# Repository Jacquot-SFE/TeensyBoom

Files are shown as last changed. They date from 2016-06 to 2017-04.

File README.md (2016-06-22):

TEENSYBOOM
---
Teensy 3.2 analog emulation drum machine.

# Organization

Supposedly all of the design artifacts will wind up in here.

If it's not here, go check the ol' [synth-drum]() repo.  It's a mess, be warned.

* **/chassis/** files for the cheek blocks & control panel
* **/TeensyBoomVoiceLibrary/** source files for the Teensy-audio-based library
* **/TeensyBoom/** the sketch files for the sequencer and stuff
* **/demo-patterns/** Some pattern files captured after playing with the sequencer a bit.  For use when you get sick of the default pattern.
* **/Documentation/** ha ha.  

## Setup & Configuration

Developed using Arduino IDE 1.6.5.  Last time I tried a newer built, it rebuilt everything everytime I clicked 'go.'

Loading using Teensy Loader 1.28.

### Installation:

Copy the _TeensyVoiceLibrary_ files to your local Arduino library directory (for me , it's C:\Users\redacted\Documents\Arduino\libraries\TeensyBoomVoiceLibrary).

Remove or rename the AudioSynthSimpleDrum in the teensy audio directory (C:\Users\byron.jacquot\Documents\Arduino\libraries\Audio\synth_simple_drum.cpp and .h).  The Boom library contains a newer version.

### Compile and Load:

I've been building for 72 MHz, non-optimized, with the assumption that we can always bump up to optimization & overclocking if we run out of resources.  It's harder to go the other way!

License Information
-------------------

This product is _**open source**_!

Please review the LICENSE.md file for license information.

Distributed as-is; no warranty is given.

It heavily leverages all of the infrastructure developed by [PJRC.com](PJRC.com).  Please support them by purchasing genuine Teensy components!  _Alibaba Teensys aren't Teensies!_

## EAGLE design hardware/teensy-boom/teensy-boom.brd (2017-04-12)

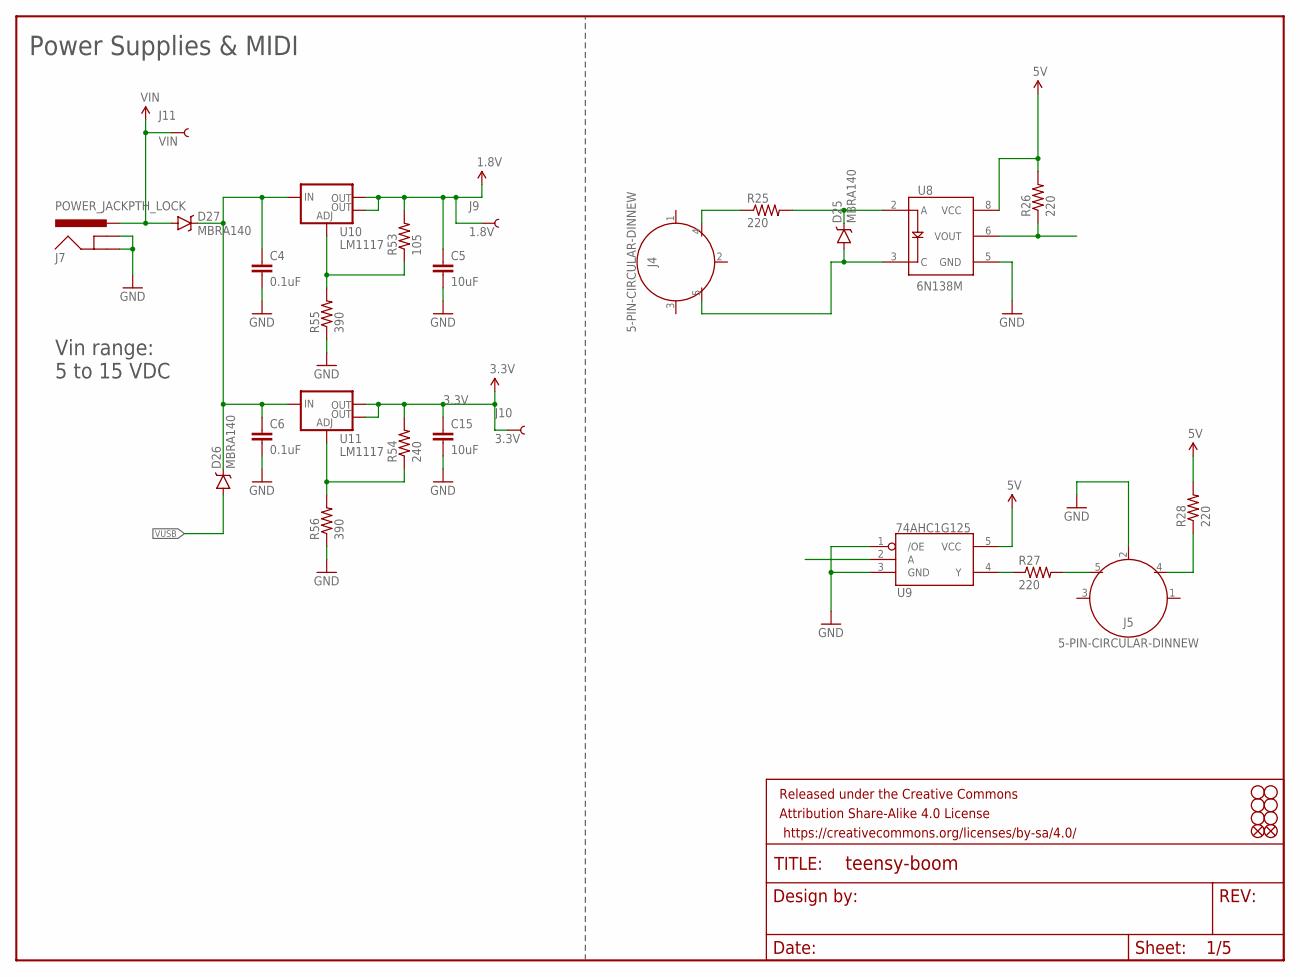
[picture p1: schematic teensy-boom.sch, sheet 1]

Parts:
C4, C6: 0.1uF; 0603-CAP
C5, C15: 10uF; 0603-CAP
D25, D26, D27: MBRA140; SMA-DIODE
FD1, FD2: FIDUCIALUFIDUCIAL; MICRO-FIDUCIAL
FRAME2: FRAME-LETTERNO_PACKAGE; DUMMY
H1, H2, H3, H4, H5, H6: STAND-OFF
J4, J5: 5-PIN-CIRCULAR-DINNEW; 5-PIN-DIN-RA-PCB-NEW
J7: POWER_JACKPTH_LOCK; POWER_JACK_PTH_LOCK
J9: 1.8V; TP_15TH
J10: 3.3V; TP_15TH
J11: VIN; TP_15TH
R25, R26, R27, R28: 220; 0603-RES
R53: 105; 0603-RES
R54: 240; 0603-RES
R55, R56: 390; 0603-RES
U8: 6N138M; 8-SMD
U9: 74AHC1G125; SOT23-5
U10, U11: LM1117; SOT223

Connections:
1.8V: C5.1, J9.P$1, R53.2, U10.2 (OUT), U10.4 (OUT); also elsewhere on the board
3.3V: C15.1, J10.P$1, R54.2, U11.2 (OUT), U11.4 (OUT); also elsewhere on the board
5V: R26.2, R28.2, U8.8 (VCC), U9.5 (VCC)
GND: C4.2, C5.2, C6.2, C15.2, J5.2, J7.GND, J7.GNDBREAK, R55.1, R56.1, U8.5 (GND), U9.1 (/OE), U9.3 (GND); also elsewhere on the board
unnamed: J4.4, R25.1
unnamed: D25.C, R25.2, U8.2 (A)
unnamed: D25.A, J4.5, U8.3 (C)
unnamed: R26.1, U8.6 (VOUT)
unnamed: R27.1, U9.4 (Y)
unnamed: J5.5, R27.2
unnamed: J5.4, R28.1
unnamed: C4.1, C6.1, D26.C, D27.C, U10.3 (IN), U11.3 (IN)
unnamed: R53.1, R55.2, U10.1 (ADJ)
unnamed: R54.1, R56.2, U11.1 (ADJ)
VIN: D27.A, J7.PWR, J11.P$1
VUSB: D26.A; also elsewhere on the board

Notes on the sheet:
Power Supplies & MIDI
Vin range: 5 to 15 VDC

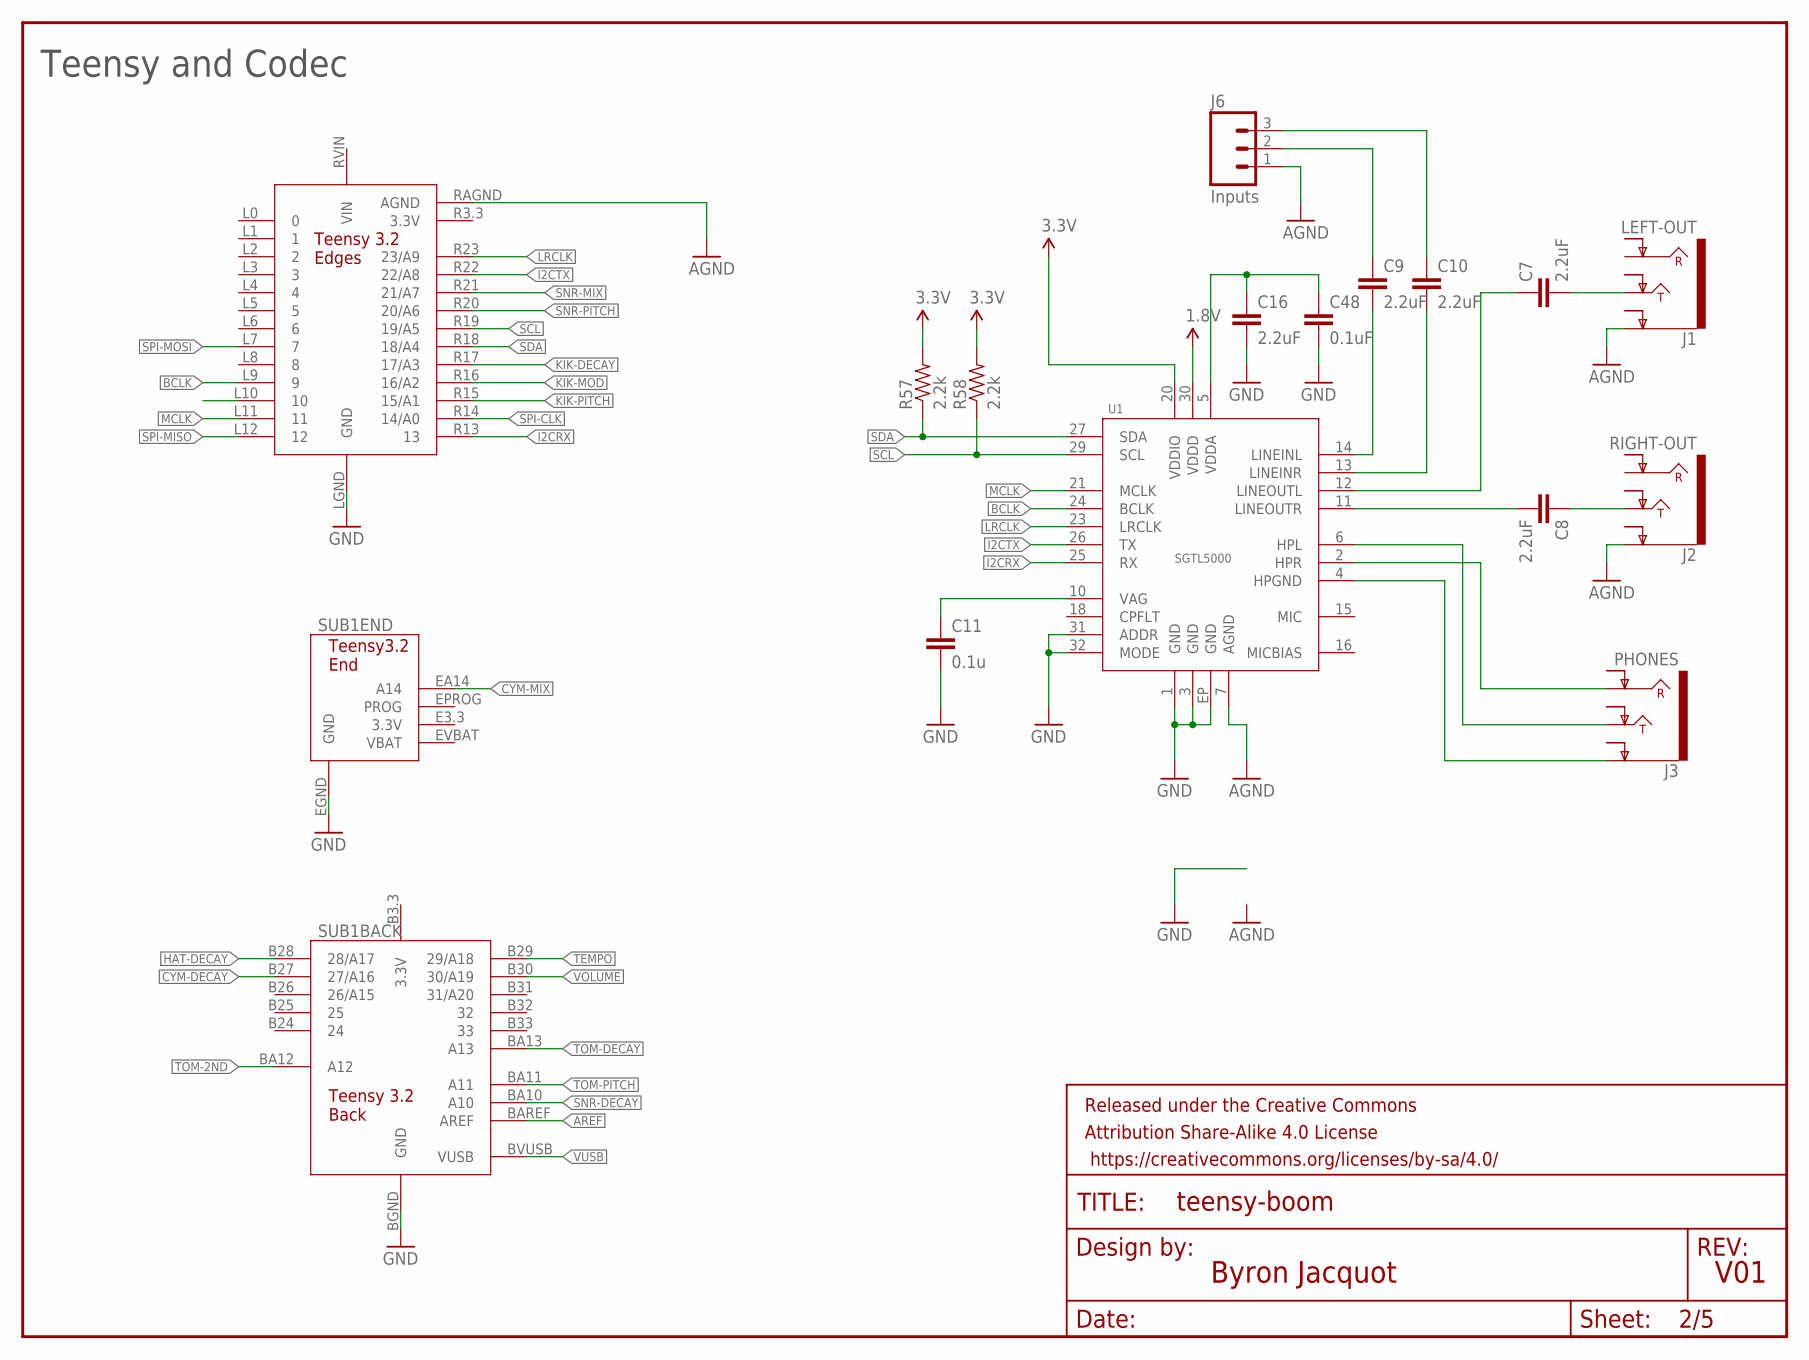
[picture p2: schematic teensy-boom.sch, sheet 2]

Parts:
C7, C8, C9, C10, C16: 2.2uF; 0805-CAP
C11: 0.1u; 0805
C48: 0.1uF; 0603-CAP
FRAME1: FRAME-LETTER; CREATIVE_COMMONS
J1: LEFT-OUT; AUDIO-JACK-.25-INCH-HORIZ-PTH
J2: RIGHT-OUT; AUDIO-JACK-.25-INCH-HORIZ-PTH
J3: PHONES; AUDIO-JACK-.25-INCH-HORIZ-PTH
J6: Inputs; 1X03_LOCK
R57, R58: 2.2k; 0603-RES
SUB1: TEENSY-3.2PTH; TEENSY-3.2
U1: SGTL5000; QFN-32

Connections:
1.8V: U1.30 (VDDD); also elsewhere on the board
3.3V: R57.2, R58.2, U1.20 (VDDIO); also elsewhere on the board
AGND: J1.SLEEVE (EARTH), J2.SLEEVE (EARTH), J6.1, SUB1.RAGND (AGND), U1.7 (AGND); also elsewhere on the board
AREF: SUB1.BAREF (AREF); also elsewhere on the board
BCLK: SUB1.L9 (9), U1.24 (BCLK)
CYM-DECAY: SUB1.B27 (27/A16); also elsewhere on the board
CYM-MIX: SUB1.EA14 (A14); also elsewhere on the board
GND: C11.2, C16.2, C48.2, SUB1.BGND (GND), SUB1.EGND (GND), SUB1.LGND (GND), U1.1 (GND), U1.3 (GND), U1.31 (ADDR), U1.32 (MODE), U1.EP (GND); also elsewhere on the board
HAT-DECAY: SUB1.B28 (28/A17); also elsewhere on the board
I2CRX: SUB1.R13 (13), U1.25 (RX)
I2CTX: SUB1.R22 (22/A8), U1.26 (TX)
KIK-DECAY: SUB1.R17 (17/A3); also elsewhere on the board
KIK-MOD: SUB1.R16 (16/A2); also elsewhere on the board
KIK-PITCH: SUB1.R15 (15/A1); also elsewhere on the board
LRCLK: SUB1.R23 (23/A9), U1.23 (LRCLK)
MCLK: SUB1.L11 (11), U1.21 (MCLK)
unnamed: C8.1, J2.TIP
unnamed: C7.2, J1.TIP
unnamed: C8.2, U1.11 (LINEOUTR)
unnamed: C7.1, U1.12 (LINEOUTL)
unnamed: C10.2, U1.13 (LINEINR)
unnamed: C9.2, U1.14 (LINEINL)
unnamed: J3.TIP, U1.6 (HPL)
unnamed: J3.RING, U1.2 (HPR)
unnamed: J3.SLEEVE (EARTH), U1.4 (HPGND)
unnamed: C9.1, J6.2
unnamed: C10.1, J6.3
unnamed: C11.1, U1.10 (VAG)
unnamed: C16.1, C48.1, U1.5 (VDDA)
SCL: R58.1, SUB1.R19 (19/A5), U1.29 (SCL)
SDA: R57.1, SUB1.R18 (18/A4), U1.27 (SDA)
SNR-DECAY: SUB1.BA10 (A10); also elsewhere on the board
SNR-MIX: SUB1.R21 (21/A7); also elsewhere on the board
SNR-PITCH: SUB1.R20 (20/A6); also elsewhere on the board
SPI-CLK: SUB1.R14 (14/A0); also elsewhere on the board
SPI-MISO: SUB1.L12 (12); also elsewhere on the board
SPI-MOSI: SUB1.L7 (7); also elsewhere on the board
TEMPO: SUB1.B29 (29/A18); also elsewhere on the board
TOM-2ND: SUB1.BA12 (A12); also elsewhere on the board
TOM-DECAY: SUB1.BA13 (A13); also elsewhere on the board
TOM-PITCH: SUB1.BA11 (A11); also elsewhere on the board
VOLUME: SUB1.B30 (30/A19); also elsewhere on the board
VUSB: SUB1.BVUSB (VUSB); also elsewhere on the board

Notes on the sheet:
V01
Byron Jacquot
Teensy and Codec

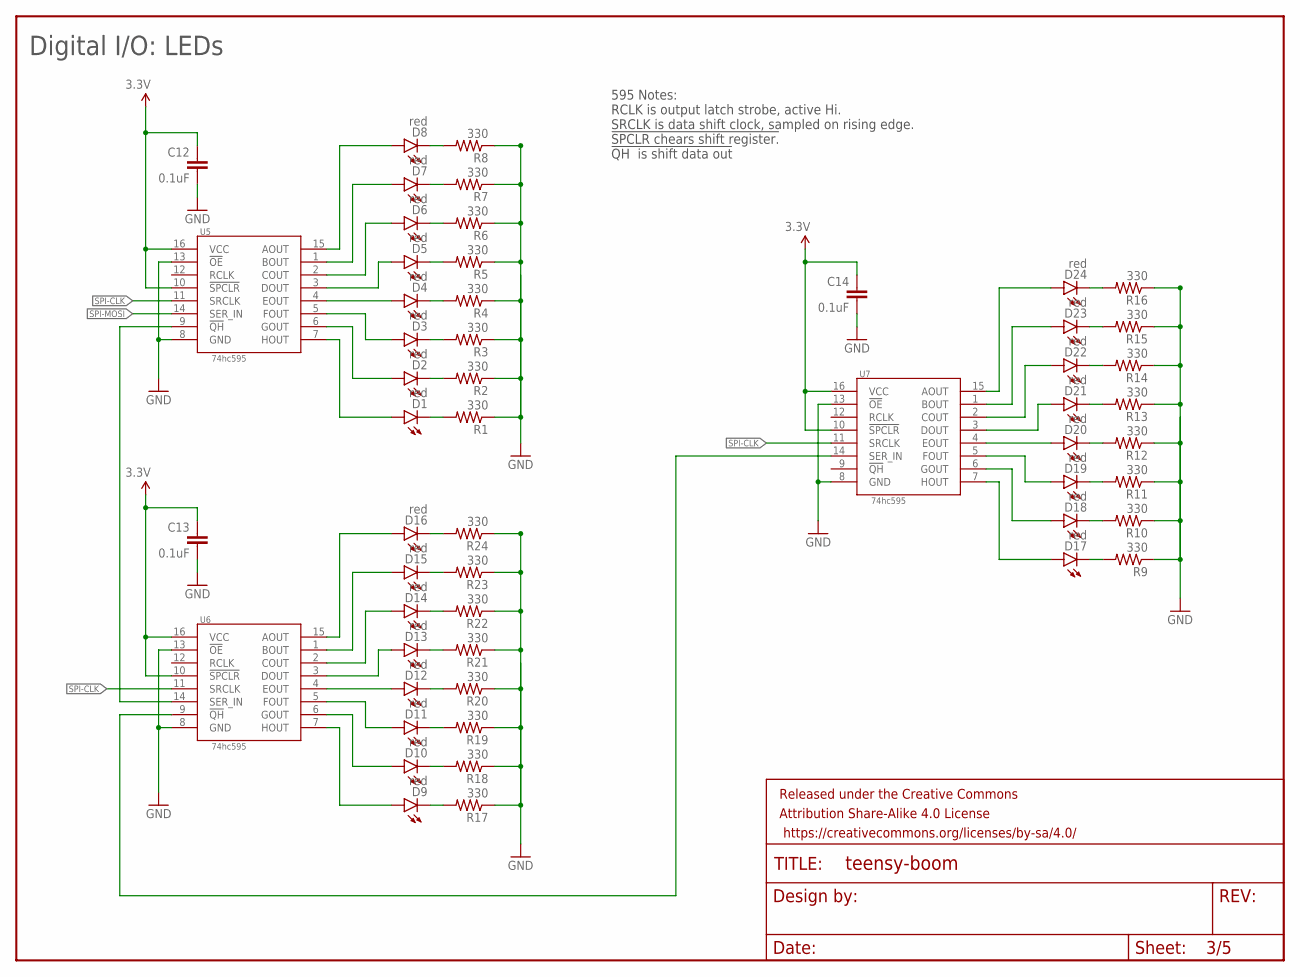
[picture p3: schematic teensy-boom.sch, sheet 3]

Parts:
C12, C13, C14: 0.1uF; 0603-CAP
D1, D2, D3, D4, D5, D6, D7, D8, D9, D10, D11, D12, D13, D14, D15, D16, D17, D18, D19, D20, D21, D22, D23, D24: red; LED3MM-NS
FRAME3: FRAME-LETTERNO_PACKAGE; DUMMY
R1, R2, R3, R4, R5, R6, R7, R8, R9, R10, R11, R12, R13, R14, R15, R16, R17, R18, R19, R20, R21, R22, R23, R24: 330; 0603-RES
U5, U6, U7: 74hc595; SO16

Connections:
3.3V: C12.1, C13.1, C14.1, U5.10 (!SPCLR), U5.16 (VCC), U6.10 (!SPCLR), U6.16 (VCC), U7.10 (!SPCLR), U7.16 (VCC); also elsewhere on the board
GND: C12.2, C13.2, C14.2, R1.1, R2.1, R3.1, R4.1, R5.1, R6.1, R7.1, R8.1, R9.1, R10.1, R11.1, R12.1, R13.1, R14.1, R15.1, R16.1, R17.1, R18.1, R19.1, R20.1, R21.1, R22.1, R23.1, R24.1, U5.8 (GND), U5.13 (!OE), U6.8 (GND), U6.13 (!OE), U7.8 (GND), U7.13 (!OE); also elsewhere on the board
unnamed: D1.K (C), R1.2
unnamed: D2.K (C), R2.2
unnamed: D3.K (C), R3.2
unnamed: D4.K (C), R4.2
unnamed: D5.K (C), R5.2
unnamed: D6.K (C), R6.2
unnamed: D7.K (C), R7.2
unnamed: D8.K (C), R8.2
unnamed: D9.K (C), R17.2
unnamed: D10.K (C), R18.2
unnamed: D11.K (C), R19.2
unnamed: D12.K (C), R20.2
unnamed: D13.K (C), R21.2
unnamed: D14.K (C), R22.2
unnamed: D15.K (C), R23.2
unnamed: D16.K (C), R24.2
unnamed: D17.K (C), R9.2
unnamed: D18.K (C), R10.2
unnamed: D19.K (C), R11.2
unnamed: D20.K (C), R12.2
unnamed: D21.K (C), R13.2
unnamed: D22.K (C), R14.2
unnamed: D23.K (C), R15.2
unnamed: D24.K (C), R16.2
unnamed: D5.A, U5.3 (DOUT)
unnamed: D4.A, U5.4 (EOUT)
unnamed: D3.A, U5.5 (FOUT)
unnamed: D2.A, U5.6 (GOUT)
unnamed: D1.A, U5.7 (HOUT)
unnamed: D6.A, U5.2 (COUT)
unnamed: D7.A, U5.1 (BOUT)
unnamed: D8.A, U5.15 (AOUT)
unnamed: D12.A, U6.4 (EOUT)
unnamed: D11.A, U6.5 (FOUT)
unnamed: D10.A, U6.6 (GOUT)
unnamed: D9.A, U6.7 (HOUT)
unnamed: D13.A, U6.3 (DOUT)
unnamed: D14.A, U6.2 (COUT)
unnamed: D15.A, U6.1 (BOUT)
unnamed: D16.A, U6.15 (AOUT)
unnamed: D20.A, U7.4 (EOUT)
unnamed: D19.A, U7.5 (FOUT)
unnamed: D18.A, U7.6 (GOUT)
unnamed: D17.A, U7.7 (HOUT)
unnamed: D21.A, U7.3 (DOUT)
unnamed: D24.A, U7.15 (AOUT)
unnamed: D23.A, U7.1 (BOUT)
unnamed: D22.A, U7.2 (COUT)
unnamed: U5.9 (!QH), U6.14 (SER_IN)
unnamed: U6.9 (!QH), U7.14 (SER_IN)
SPI-CLK: U5.11 (SRCLK); also elsewhere on the board
SPI-MOSI: U5.14 (SER_IN); also elsewhere on the board

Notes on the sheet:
Digital I/O: LEDs
595 Notes: RCLK is output latch strobe, active Hi. SRCLK is data shift clock, sampled on rising edge. !SPCLR chears shift register. !QH is shift data out

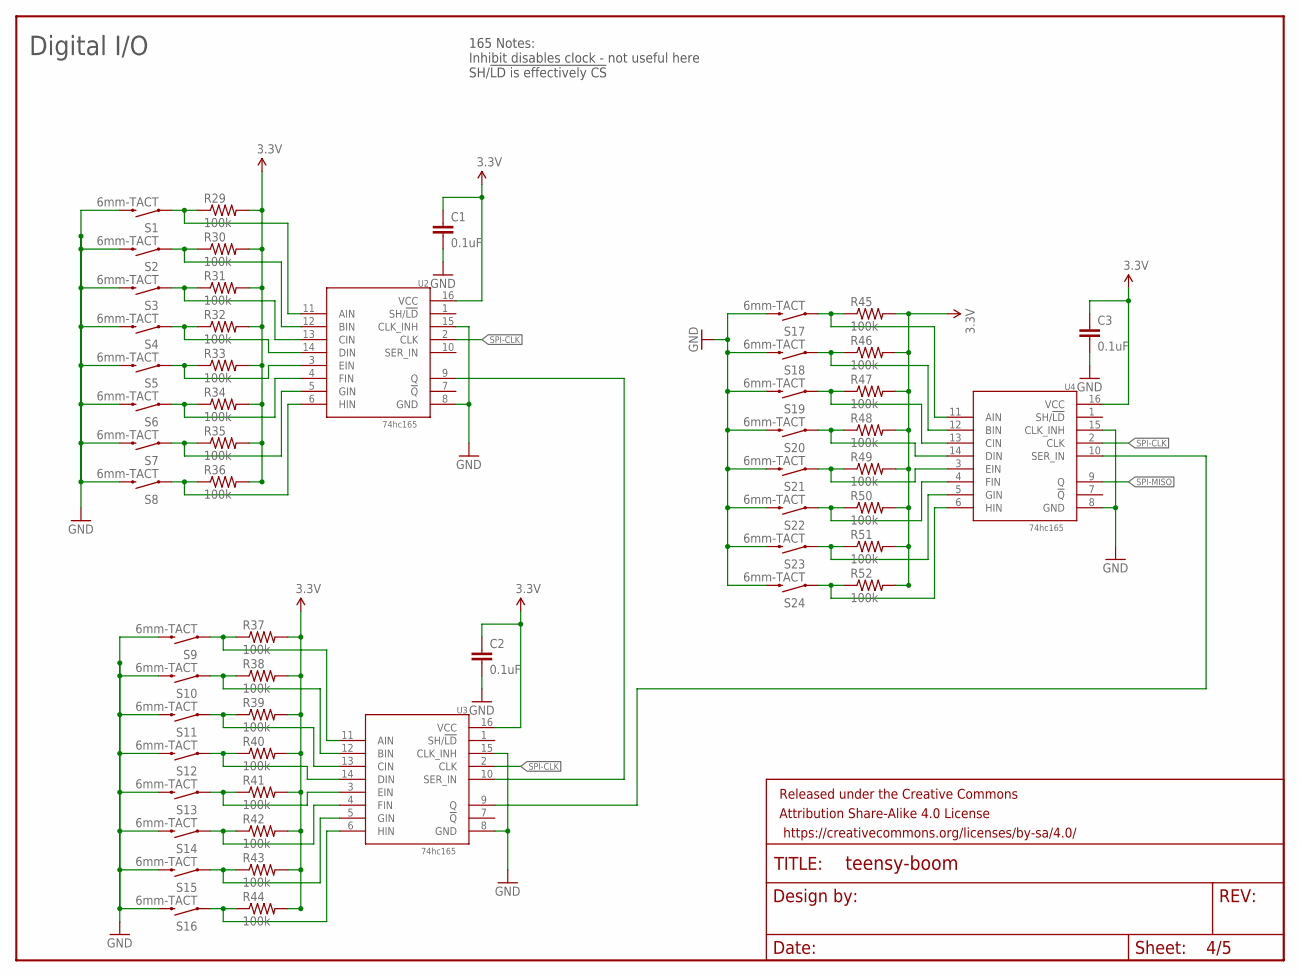
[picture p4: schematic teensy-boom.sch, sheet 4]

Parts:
C1, C2, C3: 0.1uF; 0603-CAP
FRAME5: FRAME-LETTERNO_PACKAGE; DUMMY
R29, R30, R31, R32, R33, R34, R35, R36, R37, R38, R39, R40, R41, R42, R43, R44, R45, R46, R47, R48, R49, R50, R51, R52: 100k; 0805
S1, S2, S3, S4, S5, S6, S7, S8, S9, S10, S11, S12, S13, S14, S15, S16, S17, S18, S19, S20, S21, S22, S23, S24: 6mm-TACT; TACTILE-PTH
U2, U3, U4: 74hc165; SO16

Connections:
3.3V: C1.1, C2.1, C3.1, R29.2, R30.2, R31.2, R32.2, R33.2, R34.2, R35.2, R36.2, R37.2, R38.2, R39.2, R40.2, R41.2, R42.2, R43.2, R44.2, R45.2, R46.2, R47.2, R48.2, R49.2, R50.2, R51.2, R52.2, U2.16 (VCC), U3.16 (VCC), U4.16 (VCC); also elsewhere on the board
GND: C1.2, C2.2, C3.2, S1.3 (2), S2.3 (2), S3.3 (2), S4.3 (2), S5.3 (2), S6.3 (2), S7.3 (2), S8.3 (2), S9.3 (2), S10.3 (2), S11.3 (2), S12.3 (2), S13.3 (2), S14.3 (2), S15.3 (2), S16.3 (2), S17.3 (2), S18.3 (2), S19.3 (2), S20.3 (2), S21.3 (2), S22.3 (2), S23.3 (2), S24.3 (2), U2.8 (GND), U2.15 (CLK_INH), U3.8 (GND), U3.15 (CLK_INH), U4.8 (GND), U4.15 (CLK_INH); also elsewhere on the board
unnamed: R35.1, S7.1, U2.5 (GIN)
unnamed: R29.1, S1.1, U2.11 (AIN)
unnamed: R30.1, S2.1, U2.12 (BIN)
unnamed: R31.1, S3.1, U2.13 (CIN)
unnamed: R32.1, S4.1, U2.14 (DIN)
unnamed: R33.1, S5.1, U2.3 (EIN)
unnamed: R34.1, S6.1, U2.4 (FIN)
unnamed: R36.1, S8.1, U2.6 (HIN)
unnamed: R37.1, S9.1, U3.11 (AIN)
unnamed: R38.1, S10.1, U3.12 (BIN)
unnamed: R39.1, S11.1, U3.13 (CIN)
unnamed: R40.1, S12.1, U3.14 (DIN)
unnamed: R41.1, S13.1, U3.3 (EIN)
unnamed: R42.1, S14.1, U3.4 (FIN)
unnamed: R43.1, S15.1, U3.5 (GIN)
unnamed: R44.1, S16.1, U3.6 (HIN)
unnamed: R45.1, S17.1, U4.11 (AIN)
unnamed: R46.1, S18.1, U4.12 (BIN)
unnamed: R47.1, S19.1, U4.13 (CIN)
unnamed: R48.1, S20.1, U4.14 (DIN)
unnamed: R49.1, S21.1, U4.3 (EIN)
unnamed: R50.1, S22.1, U4.4 (FIN)
unnamed: R51.1, S23.1, U4.5 (GIN)
unnamed: U2.9 (Q), U3.10 (SER_IN)
unnamed: U3.9 (Q), U4.10 (SER_IN)
unnamed: R52.1, S24.1, U4.6 (HIN)
SPI-CLK: U2.2 (CLK); also elsewhere on the board
SPI-MISO: U4.9 (Q); also elsewhere on the board

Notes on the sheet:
Digital I/O
165 Notes: Inhibit disables clock - not useful here SH/!LD is effectively CS

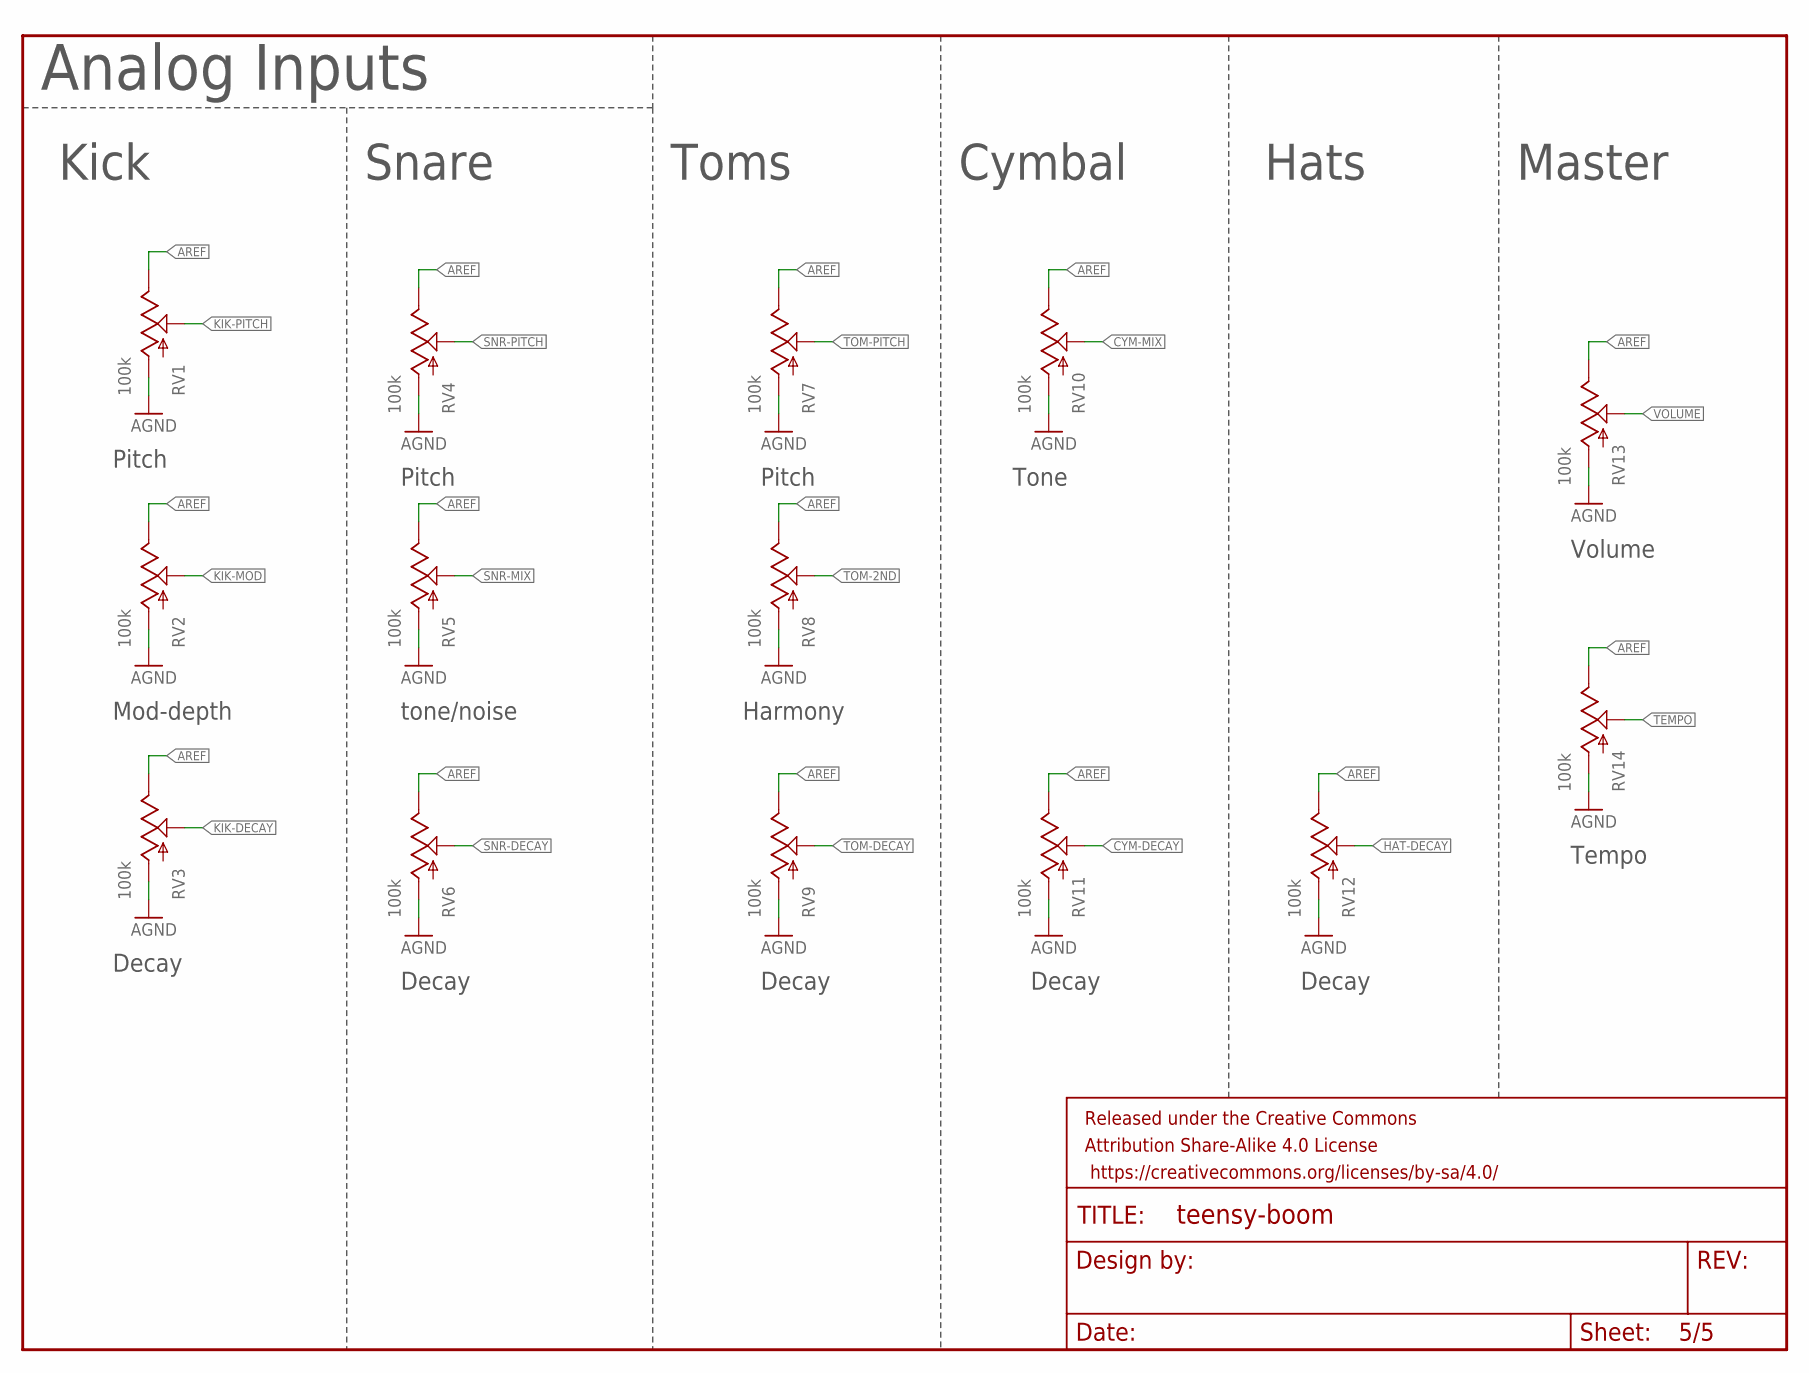
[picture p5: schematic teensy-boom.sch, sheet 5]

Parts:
FRAME4: FRAME-LETTERNO_PACKAGE; DUMMY
RV1, RV2, RV3, RV4, RV5, RV6, RV7, RV8, RV9, RV10, RV11, RV12, RV13, RV14: 100k; ALPS_POT_KIT

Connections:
AGND: RV1.P$3 (A), RV2.P$3 (A), RV3.P$3 (A), RV4.P$3 (A), RV5.P$3 (A), RV6.P$3 (A), RV7.P$3 (A), RV8.P$3 (A), RV9.P$3 (A), RV10.P$3 (A), RV11.P$3 (A), RV12.P$3 (A), RV13.P$3 (A), RV14.P$3 (A); also elsewhere on the board
AREF: RV1.P$1 (E), RV2.P$1 (E), RV3.P$1 (E), RV4.P$1 (E), RV5.P$1 (E), RV6.P$1 (E), RV7.P$1 (E), RV8.P$1 (E), RV9.P$1 (E), RV10.P$1 (E), RV11.P$1 (E), RV12.P$1 (E), RV13.P$1 (E), RV14.P$1 (E); also elsewhere on the board
CYM-DECAY: RV11.P$2 (S); also elsewhere on the board
CYM-MIX: RV10.P$2 (S); also elsewhere on the board
HAT-DECAY: RV12.P$2 (S); also elsewhere on the board
KIK-DECAY: RV3.P$2 (S); also elsewhere on the board
KIK-MOD: RV2.P$2 (S); also elsewhere on the board
KIK-PITCH: RV1.P$2 (S); also elsewhere on the board
SNR-DECAY: RV6.P$2 (S); also elsewhere on the board
SNR-MIX: RV5.P$2 (S); also elsewhere on the board
SNR-PITCH: RV4.P$2 (S); also elsewhere on the board
TEMPO: RV14.P$2 (S); also elsewhere on the board
TOM-2ND: RV8.P$2 (S); also elsewhere on the board
TOM-DECAY: RV9.P$2 (S); also elsewhere on the board
TOM-PITCH: RV7.P$2 (S); also elsewhere on the board
VOLUME: RV13.P$2 (S); also elsewhere on the board

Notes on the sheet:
Analog Inputs
Tempo
Volume
Pitch
Mod-depth
Decay
tone/noise
Harmony
Tone
Kick
Snare
Toms
Cymbal
Hats
Master

Board: 2 copper layers, 175 parts (94 on the bottom side), 131 nets, no tracks yet.

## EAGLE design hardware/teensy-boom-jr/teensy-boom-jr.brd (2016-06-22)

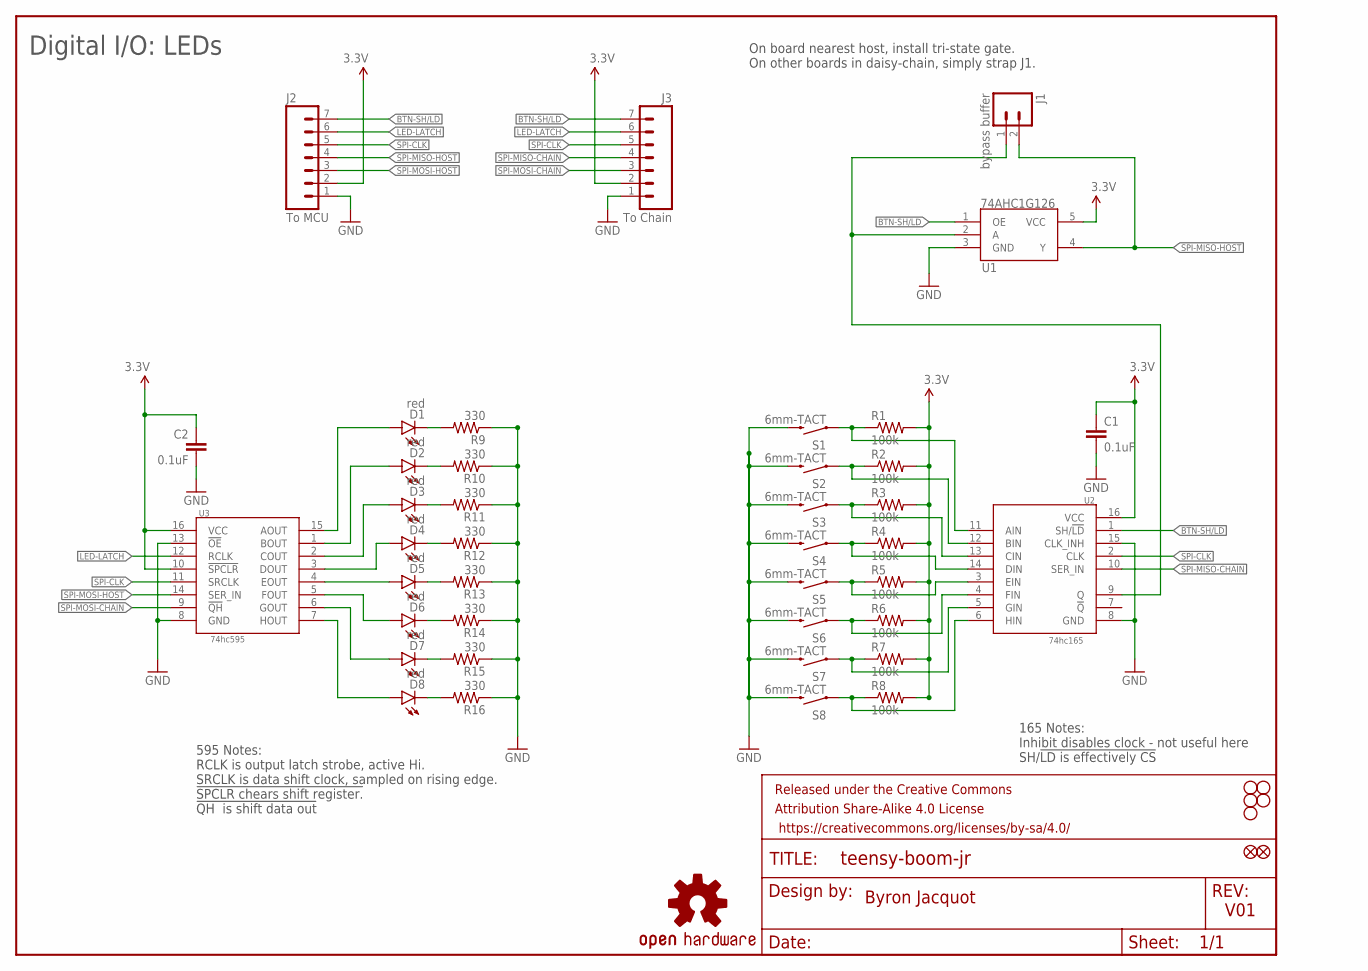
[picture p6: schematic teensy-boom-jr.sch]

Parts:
C1, C2: 0.1uF; 0603-CAP
D1, D2, D3, D4, D5, D6, D7, D8: red; LED3MM-NS
FD1, FD2: FIDUCIALUFIDUCIAL; MICRO-FIDUCIAL
FRAME1: FRAME-LETTER; CREATIVE_COMMONS
H1, H2, H3, H4, H5: STAND-OFF
J1: bypass buffer; 1X02_NO_SILK
J2: To MCU; 1X07_NO_SILK
J3: To Chain; 1X07_NO_SILK
LOGO1: OSHW-LOGOS; OSHW-LOGO-S
R1, R2, R3, R4, R5, R6, R7, R8: 100k; 0805
R9, R10, R11, R12, R13, R14, R15, R16: 330; 0603-RES
S1, S2, S3, S4, S5, S6, S7, S8: 6mm-TACT; TACTILE-PTH-12MM
U1: 74AHC1G126; SOT23-5
U2: 74hc165; SO16
U3: 74hc595; SO16

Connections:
3.3V: C1.1, C2.1, J2.2, J3.2, R1.2, R2.2, R3.2, R4.2, R5.2, R6.2, R7.2, R8.2, U1.5 (VCC), U2.16 (VCC), U3.10 (!SPCLR), U3.16 (VCC)
BTN-SH/LD: J2.7, J3.7, U1.1 (OE), U2.1 (SH/!LD)
GND: C1.2, C2.2, J2.1, J3.1, R9.1, R10.1, R11.1, R12.1, R13.1, R14.1, R15.1, R16.1, S1.3 (2), S2.3 (2), S3.3 (2), S4.3 (2), S5.3 (2), S6.3 (2), S7.3 (2), S8.3 (2), U1.3 (GND), U2.8 (GND), U2.15 (CLK_INH), U3.8 (GND), U3.13 (!OE)
LED-LATCH: J2.6, J3.6, U3.12 (RCLK)
unnamed: R1.1, S1.1, U2.11 (AIN)
unnamed: R2.1, S2.1, U2.12 (BIN)
unnamed: R3.1, S3.1, U2.13 (CIN)
unnamed: R4.1, S4.1, U2.14 (DIN)
unnamed: D8.K (C), R16.2
unnamed: R5.1, S5.1, U2.3 (EIN)
unnamed: R6.1, S6.1, U2.4 (FIN)
unnamed: R7.1, S7.1, U2.5 (GIN)
unnamed: D7.K (C), R15.2
unnamed: D6.K (C), R14.2
unnamed: D5.K (C), R13.2
unnamed: D4.K (C), R12.2
unnamed: D3.K (C), R11.2
unnamed: D2.K (C), R10.2
unnamed: D1.K (C), R9.2
unnamed: R8.1, S8.1, U2.6 (HIN)
unnamed: J1.1, U1.2 (A), U2.9 (Q)
unnamed: D4.A, U3.3 (DOUT)
unnamed: D5.A, U3.4 (EOUT)
unnamed: D6.A, U3.5 (FOUT)
unnamed: D7.A, U3.6 (GOUT)
unnamed: D8.A, U3.7 (HOUT)
unnamed: D3.A, U3.2 (COUT)
unnamed: D2.A, U3.1 (BOUT)
unnamed: D1.A, U3.15 (AOUT)
SPI-CLK: J2.5, J3.5, U2.2 (CLK), U3.11 (SRCLK)
SPI-MISO-CHAIN: J3.4, U2.10 (SER_IN)
SPI-MISO-HOST: J1.2, J2.4, U1.4 (Y)
SPI-MOSI-CHAIN: J3.3, U3.9 (!QH)
SPI-MOSI-HOST: J2.3, U3.14 (SER_IN)

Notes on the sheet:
Digital I/O: LEDs
595 Notes: RCLK is output latch strobe, active Hi. SRCLK is data shift clock, sampled on rising edge. !SPCLR chears shift register. !QH is shift data out
On board nearest host, install tri-state gate. On other boards in daisy-chain, simply strap J1.
165 Notes: Inhibit disables clock - not useful here SH/!LD is effectively CS
Byron Jacquot
V01

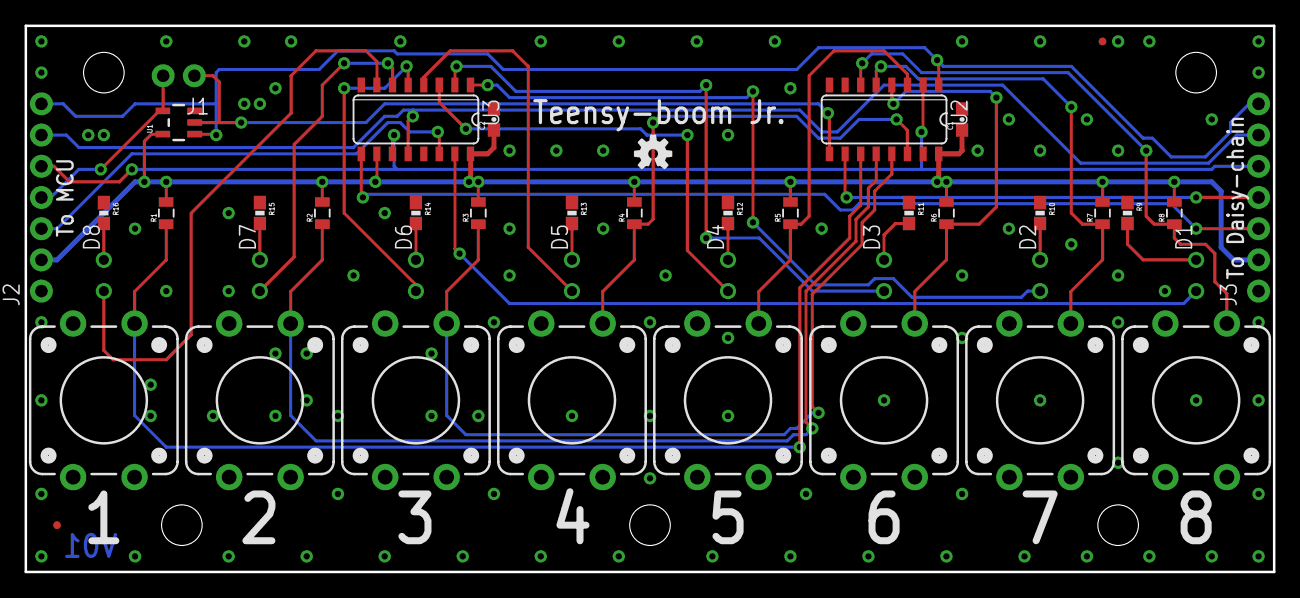
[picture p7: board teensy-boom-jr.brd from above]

Board: 2 copper layers, 101.6 x 44.5 mm, 49 parts (0 on the bottom side), 34 nets.

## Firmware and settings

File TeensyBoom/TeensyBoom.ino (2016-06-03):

#include <Synth-Clatter.h>
#include <Synth-Decay.h>
#include <Synth-DrumHeart.h>
#include <synth_simple_drum.h>
#include <TeensyBoomVoiceLibrary.h>

#include <Audio.h>
#include <Wire.h>
#include <SPI.h>
#include <SD.h>
#include <SerialFlash.h>


#include "panel-scanner.h"
#include "editor.h"
#include "pattern.h"
#include "player.h"
#include "voice.h"


// Appp construct singletons
PanelScanner theScanner;
Editor       theEditor;
Pattern      thePattern; // TBD: multidimensional...
Player       thePlayer;


void setup() {
  // put your setup code here, to run once:

  Serial.begin(115200);

  delay(1500);

  Serial.println("Setup");

  pinMode(15, INPUT); // Volume pot pin?

  // SD CARD & general SPI inits
  // Initialize the SD card
  SPI.setMOSI(7);
  SPI.setSCK(14);

  // This sets the chip selects for the panel
  // to OFF.  Gotta do it before SD init, else the panels contend!
  theScanner.initScanning();


  if (!(SD.begin(10)))
  {
    Serial.println("Unable to access the SD card");
  }
  else
  {
    Serial.println("SD card begin worked");
  }

  if (SD.exists("test.txt"))
  {
    Serial.println("found test.txt file");
  }
  else
  {
    Serial.println("Didn't find test file?");
  }


  theEditor.setMode(Editor::eMODE_PATT_SEL);

  // audio library init
  AudioMemory(20);

  //next = millis() + 1000;

  // read panel before we start to run
  //paramUpdate();

  voiceInit();

  delay(500);

  Serial.println("Setup Complete");
}

void loop()
{
  uint32_t now = millis();
  static uint32_t then;

#if 1
  // put your main code here, to run repeatedly:

  paramUpdate1();// kik,snr,hat
  paramUpdate2();// toms, shaker
  paramUpdate3();// master volume & tempo

  if (now > then)
  {
    thePlayer.tick();
  }

  if (now % 5 == 0)
  {
    theScanner.tick();
  }

  if (now % 5000 == 0)
  {
    //theScanner.dumpLEDs();


    Serial.print("Diagnostics: ");
    Serial.print(" max, buffs: ");
    Serial.print(AudioProcessorUsageMax());
    Serial.print(" ");
    Serial.println(AudioMemoryUsageMax());
    AudioProcessorUsageMaxReset();
  }

  then = now;
#endif
}

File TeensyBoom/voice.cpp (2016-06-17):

#include "voice.h"

#include <TeensyBoomVoiceLibrary.h>

//#include "Synth-Clatter.h"
//#include "Synth-Decay.h"
//#include "Synth-DrumHeart.h"
//#include "synth_simple_drum.h"

#include "player.h"  // required so we can update tempo param from knob update func.

extern Player thePlayer;

#define HAT
#define KICK
#define SNARE
#define TOM
#define SHAKER
#define BELL
#define CYMBAL
#define CLAP

// Used by multiple instruments:
AudioSynthNoiseWhite   noise;

#ifdef HAT
// hats
AudioSynthClatter      clat1;
AudioSynthDecay        hatdecay;
AudioFilterBiquad      hatfilter;
AudioEffectMultiply    hatmult;
#endif

#ifdef BELL
AudioSynthDecay        belldecay;
AudioEffectMultiply    bellmult;
#endif

#ifdef KICK
// kick
AudioSynthSimpleDrum     kick;
#endif

#ifdef SNARE
// snare
AudioSynthDrumHeart    snare;
AudioMixer4            snaremix;
AudioEffectMultiply    snaremult;
#endif

#ifdef TOM
// tom
AudioSynthSimpleDrum   tom;
#endif

#ifdef SHAKER
// shaker
AudioSynthDecay        shakedecay;
AudioFilterBiquad      shakefilter;
AudioEffectMultiply    shakemult;
#endif

#ifdef CYMBAL
AudioSynthDecay        cymbaldecay;
AudioFilterBiquad      cymbalfilter;
AudioEffectMultiply    cymbalmult;
#endif

#ifdef CLAP
AudioSynthDecay        clapdecay;
AudioEffectMultiply    clapmult;
AudioFilterBiquad      clapfilter;
AudioEffectClapEnvelope clapenv;
#endif

// outputs
AudioMixer4            mixer1;
AudioMixer4            mixer2;
AudioMixer4            mixer3;

// Master volume control between mixers and output,
// because the output level controls are independent between 
// phones and line outputs.
AudioEffectMultiply    mastervol;
AudioSynthWaveformDc   volcontrol;        

AudioOutputI2S           i2s1;           //xy=968,448

#ifdef HAT
AudioConnection          patchCord01(clat1, 0, hatfilter, 0);
AudioConnection          patchCord02(hatfilter, 0, hatmult, 0);
//AudioConnection          patchCord03(hatfilter, 0, hatmult, 0);
//AudioConnection          patchCord01(hatdecay, 0, hatmult, 0);
AudioConnection          patchCord03(hatdecay, 0, hatmult, 1);
AudioConnection          patchCord90(hatmult, 0, mixer1, 0);
#endif

#ifdef BELL
AudioConnection          patchCord04(clat1, 1, bellmult, 0);
AudioConnection          patchCord05(belldecay, 0, bellmult, 1);
AudioConnection          patchCord96(bellmult, 0,  mixer2, 2);
#endif

#ifdef KICK
AudioConnection          patchCord10(kick, 0, mixer1, 1);
#endif

#ifdef SNARE
AudioConnection          patchCord20(noise, 0, snaremix, 0);
AudioConnection          patchCord21(snare, 0, snaremix, 1);
AudioConnection          patchCord22(snare, 1, snaremult, 1);
AudioConnection          patchCord23(snaremix, 0, snaremult, 0);
AudioConnection          patchCord92(snaremult, 0, mixer1, 2);
#endif

#ifdef TOM
AudioConnection          patchCord30(tom, 0, mixer2, 0);
#endif

#ifdef SHAKER
AudioConnection          patchCord40(noise, 0, shakefilter, 0);
AudioConnection          patchCord41(shakefilter, 0, shakemult, 0);
AudioConnection          patchCord42(shakedecay, 0, shakemult, 1);
AudioConnection          patchCord95(shakemult, 0, mixer2, 1);
#endif

#ifdef CYMBAL
AudioConnection          patchCord50(clat1, 0, cymbalfilter, 0);
AudioConnection          patchCord51(cymbalfilter, cymbalmult);
AudioConnection          patchCord52(cymbaldecay, 0, cymbalmult, 1);
AudioConnection          patchCord97(cymbalmult, 0, mixer3, 2);
#endif

#ifdef CLAP
AudioConnection          patchCord60(noise, 0, clapenv, 0);
AudioConnection          patchCord61(clapenv, 0, mixer3, 0);
AudioConnection          patchCord62(noise, 0, clapfilter, 0);
AudioConnection          patchCord63(clapfilter, 0, clapmult, 0);
AudioConnection          patchCord64(clapdecay, 0, clapmult, 1);
AudioConnection          patchCord65(clapmult, 0, mixer3, 1);
#endif

AudioConnection          patchCord93(mixer2, 0, mixer1, 3);
AudioConnection          patchCord967(mixer3, 0, mixer2, 3);

AudioConnection          patchCord965(mixer1, 0, mastervol, 0);
AudioConnection          patchCord966(volcontrol, 0 , mastervol, 1);

AudioConnection          patchCord98(mastervol, 0, i2s1, 0);
AudioConnection          patchCord99(mastervol, 0, i2s1, 1);

AudioControlSGTL5000     sgtl5000_1;




// Globals for params on shared voices
uint16_t openlen, closedlen;
uint16_t t1, t2, t3;

void voiceInit()
{
  AudioNoInterrupts();

  sgtl5000_1.enable();
  sgtl5000_1.volume(0.7);
  sgtl5000_1.lineOutLevel(13);

  paramInit();

  AudioInterrupts();

}

void paramInit()
{
  // common to severl instruments
  noise.amplitude(0.5);
  
#ifdef HAT
  // hat stuff
  //clat1; - no params
  //hatdecay.length(150);
  openlen = 300;
  closedlen = 50;
  hatfilter.setHighpass(0, 700, 0.2);
  hatfilter.setLowpass(1, 10000, 0.8);

  //hatdecay.frequency(1500);
  //hatdecay.length(50);
#endif

#ifdef BELL
  belldecay.length(333);
#endif

#ifdef KICK
  // kick
  kick.frequency(60);
  kick.length(100);
  kick.pitchMod(0x2f0); // 0x200 is no mod...
#endif

#ifdef SNARE
  // snare
  snare.frequency(200);
  snare.length(100);
  snare.second(true);
  snare.pitchMod(0x280);
  snaremix.gain(0, 0.75);
  snaremix.gain(1, 0.5);
#endif

#ifdef TOM
  // tom
  //tom.frequency(80);
  t1 = 60;
  tom.secondMix(1.0);
  tom.length(250);
  tom.pitchMod(0.75);
#endif

#ifdef SHAKER  
  // shaker
  shakefilter.setLowpass(0, 3500, 0.7);
  shakefilter.setHighpass(1, 400, 0.3);
  shakedecay.length(50);
#endif

#ifdef CYMBAL
  //cymbalfilter.setLowpass(0, 4500, 0.3);
  //cymbalfilter.setHighpass(1, 770, 0.7);
  cymbalfilter.setBandpass(0, 3000, .2);
  cymbaldecay.length(1000);
#endif

#ifdef CLAP
  clapdecay.length(200); 
  mixer3.gain(0, 0.5);
  mixer3.gain(1, 0.4);
  clapfilter.setLowpass(0, 6500, 0.4);
  clapfilter.setHighpass(1, 200, 0.3);
#endif

  // Master
  mixer1.gain(0, 0.75);// hat
  mixer1.gain(1, 0.75);// kik
  mixer1.gain(2, 0.65);// snr
  mixer1.gain(3, 0.75);// mix2
  
  mixer2.gain(0, 0.75);// tom
  mixer2.gain(1, 0.3);//shaker
  mixer2.gain(2, 0.5);// bell
  mixer2.gain(3, 0.75);// mix3

  // 0 and 1 are set in the clap portion, above.
  mixer3.gain(2, 0.75);//cymbal
}

void paramUpdate1()
{
  uint16_t   pitch, mod, len;
  uint16_t   snpitch, snmix, snlen;
  uint16_t   ohdec, chdec;

  pitch = analogRead(A1);
  mod = analogRead(A12);
  len = analogRead(A13);

  snpitch = analogRead(A2);
  snmix = analogRead(A3);
  snlen = analogRead(A14);

  ohdec = analogRead(A6);
  chdec = analogRead(A16);

#ifdef KICK
  kick.frequency(30 + (pitch >> 3));
  kick.pitchMod((float)mod/0x3ff);
  kick.length(len + 10);
#endif
#ifdef SNARE
  float mix = (float)snmix / 1024.0;
  snare.frequency(80 + (snpitch >> 2));
  snaremix.gain(0, 1.0 - mix);
  snaremix.gain(1, mix);
  snare.length((snlen/2) + 10);
#endif
#ifdef HAT
  openlen = (ohdec/2) + 10;
  closedlen = (chdec/2) + 10;
#endif  
}
#if 1
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

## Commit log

2016-06-03 Initial source file commit.
    It's not building...yet...just a waypoint.
    [tempo-math.ods]
2016-06-03 Maybe it's building now?
    Again, the problem stems from too many copies of the files floating
    around.
    [Synth-DrumHeart.cpp, TeensyBoom.ino]
2016-06-17 Fixing stuck LEDs in voice selection mode.
2016-06-17 Reworking voice controls.
    Toms now on 4 knobs,
    Cymbal adds 2.
    [voice.cpp]
2016-06-22 Adding Teensy-boom-jr I/O PCB files
    [teensy-boom-jr.brd, teensy-boom-jr.sch]
2017-04-12 Adding files that have been sitting here for a long time...
    [teensy-boom.brd, teensy-boom.sch]

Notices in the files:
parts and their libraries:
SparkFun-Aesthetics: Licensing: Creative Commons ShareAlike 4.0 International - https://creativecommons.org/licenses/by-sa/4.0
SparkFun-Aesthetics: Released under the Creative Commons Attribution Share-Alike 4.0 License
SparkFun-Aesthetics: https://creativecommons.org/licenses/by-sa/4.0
